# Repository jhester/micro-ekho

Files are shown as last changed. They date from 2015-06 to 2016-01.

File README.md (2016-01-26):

Micro Ekho
========

#### Summary
Micro Ekhos are simply miniature, battery powered, deployable versions of [Ekho](https://github.com/jhester/ekho) that can be put placed in energy environments of interest for extended periods of time. They transmit IV curve data over a Sub 1GHz frequency to a basestation, that collects and forwards to a desktop, a phone, or stores all data to an SD card.

This repo holds the hardware files, firmware (basestation, and node), mobile app viewing software (iOs, Android) and desktop viewing software, for Micro Ekho devices.

#### What is Ekho?
Ekho is a energy environment recorder, and emulator for the Internet of Things. It lets scientists and developers who work with tiny, batteryless, energy harevsting devices (think solar panels, piezos, peltier, RFID) have a repeatable testing environment. Without Ekho, verifying functionality for certain energy conditions, is impossible.

Our paper, "Ekho: Realistic and Repeatable Experimentation for Tiny Energy-Harvesting Sensors" describes the design and evaluation of a new tool for recording and replaying energy harvesting conditions. Energy harvesting is a necessity for many small, embedded sensing devices, that must operate maintenance-free for long periods of time. However, understanding how the environment changes and it's effects on device behavior has always been a source of frustration. Ekho allows system designers working with ultra low power devices, to realistically predict how new hardware and software configurations will perform before deployment. By taking advantage of electrical characteristics all energy sources share, Ekho is able to emulate many different energy sources (e.g., Solar, RF, Thermal, and Vibrational) and takes much of the guesswork out of experimentation with tiny, energy harvesting sensing systems.

This paper received the BEST PAPER Award at the 12th ACM Conference on Embedded Networked Sensor Systems (SenSys 2014).

For more information on the concept, design, and evaluation of Ekho, checkout [my website](http://josiahhester.comr).

#### Contents
The "basestation" aggregates the data from multiple "nodes," then sends this to the client application (which can be on a phone, tablet, or desktop) or logs to an SD card. Embedded C on a Teensy ARM chip.

The "desktop" folder contains an electron app that displays the data gathered.

The "hardware" folder contains all the EAGLE files for the micro ekho hardware.

The "mobile" renders the aggregate data on a screen, in real time. Written with apache cordova, HTML, CSS, JavaScript.

The "node" folder holds all the code for the Micro Ekho nodes that are attached to energy harvesters. These nodes send IV data to the "basestation" over the radio. Embedded C on an MSP430.

### Getting Started
Currently, this project is very much in progress, please contact me for more information, or raise an Issue.

#### License
Except for the desktop application made with Electron, everything else is MIT.

The MIT License (MIT)
Copyright (c) 2016 Josiah Hester

Permission is hereby granted, free of charge, to any person obtaining a copy of this software and associated documentation files (the "Software"), to deal in the Software without restriction, including without limitation the rights to use, copy, modify, merge, publish, distribute, sublicense, and/or sell copies of the Software, and to permit persons to whom the Software is furnished to do so, subject to the following conditions:

The above copyright notice and this permission notice shall be included in all copies or substantial portions of the Software.

THE SOFTWARE IS PROVIDED "AS IS", WITHOUT WARRANTY OF ANY KIND, EXPRESS OR IMPLIED, INCLUDING BUT NOT LIMITED TO THE WARRANTIES OF MERCHANTABILITY, FITNESS FOR A PARTICULAR PURPOSE AND NONINFRINGEMENT. IN NO EVENT SHALL THE AUTHORS OR COPYRIGHT HOLDERS BE LIABLE FOR ANY CLAIM, DAMAGES OR OTHER LIABILITY, WHETHER IN AN ACTION OF CONTRACT, TORT OR OTHERWISE, ARISING FROM, OUT OF OR IN CONNECTION WITH THE SOFTWARE OR THE USE OR OTHER DEALINGS IN THE SOFTWARE.

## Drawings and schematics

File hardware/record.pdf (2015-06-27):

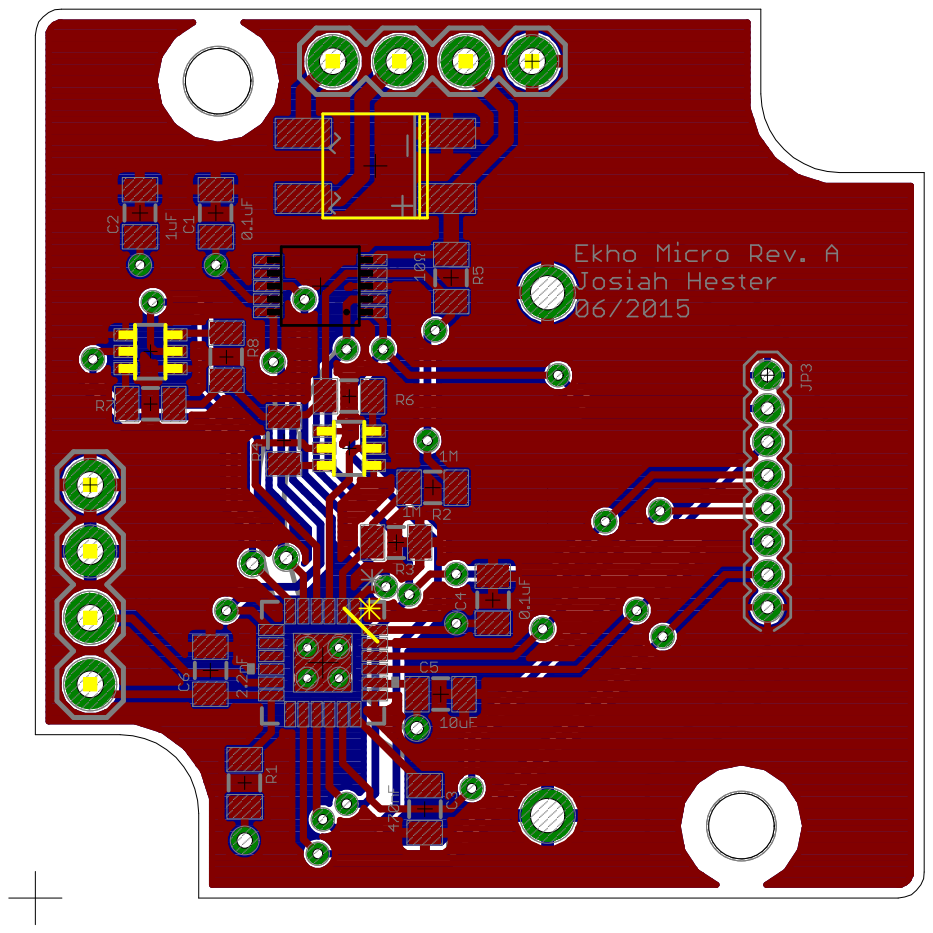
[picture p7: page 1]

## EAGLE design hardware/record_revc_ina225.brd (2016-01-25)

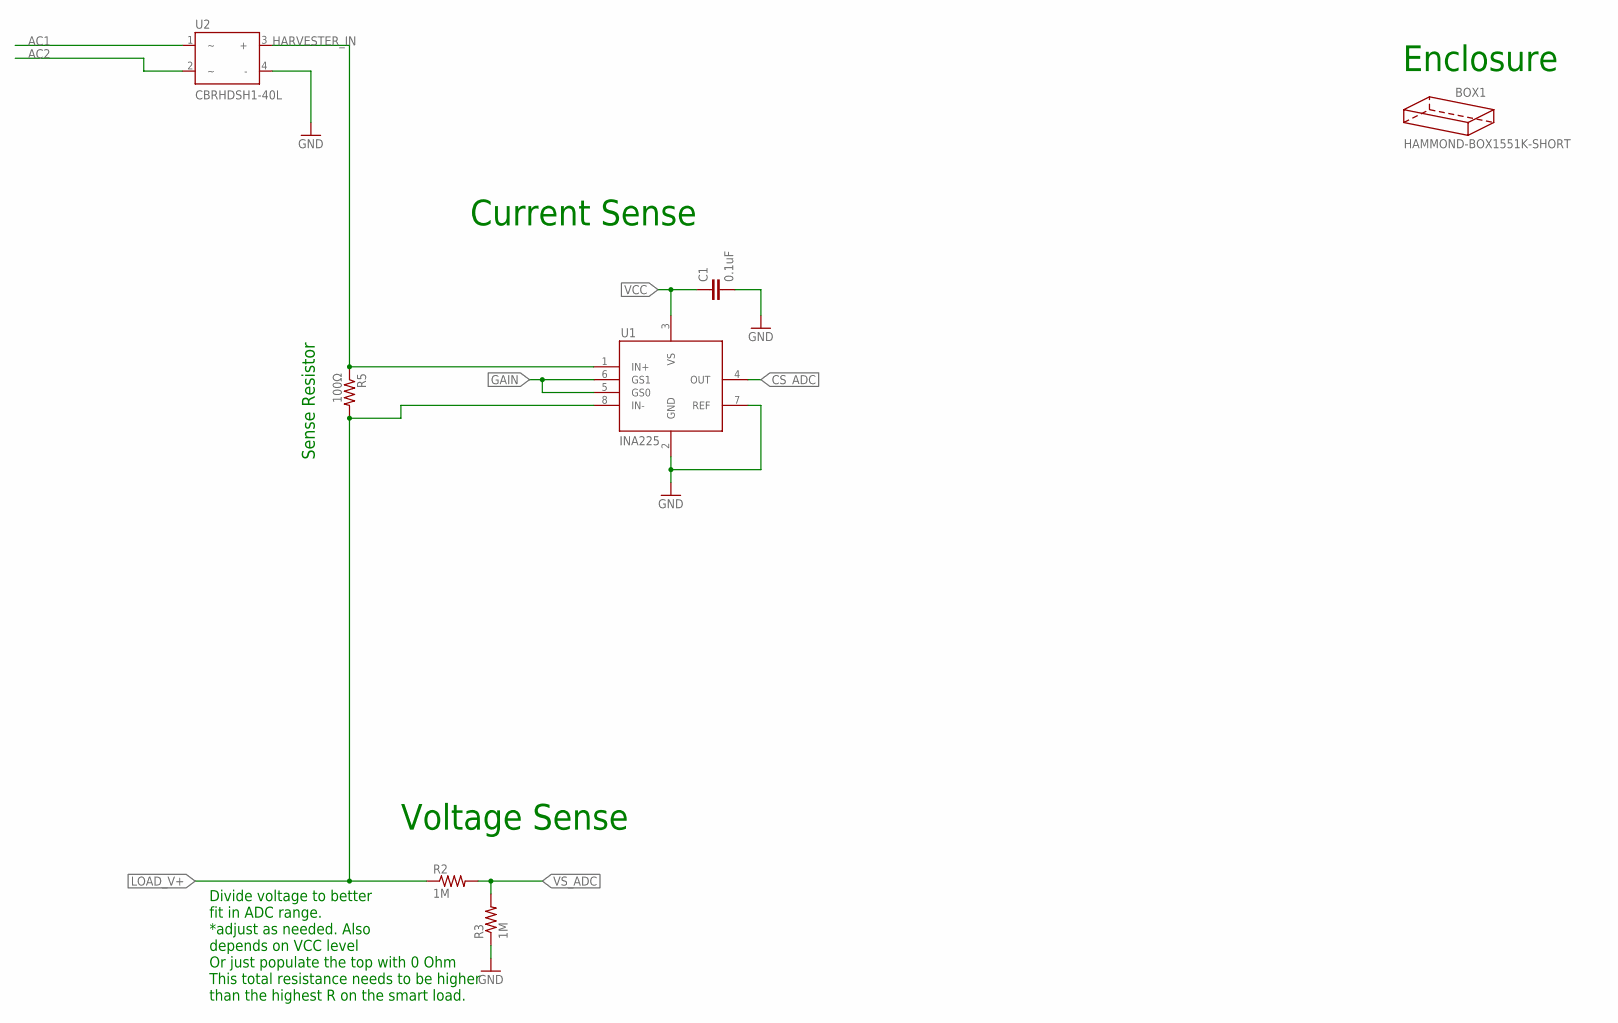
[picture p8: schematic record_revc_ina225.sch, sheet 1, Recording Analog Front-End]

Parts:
BOX1: HAMMOND-BOX1551K-SHORT; 1551K-SHORT
C1: 0.1uF; C0805
R2, R3: 1M; 0805
R5: 100Ω; 0805
U1: INA225; MSOP8
U2: CBRHDSH1-40L; HD_DIP4

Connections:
AC1: U2.1; also elsewhere on the board
AC2: U2.2; also elsewhere on the board
CS_ADC: U1.4 (OUT); also elsewhere on the board
GAIN: U1.5 (GS0), U1.6 (GS1); also elsewhere on the board
GND: C1.2, R3.1, U1.2 (GND), U1.7 (REF), U2.4 (-); also elsewhere on the board
HARVESTER_IN: R5.1, U1.1 (IN+), U2.3 (+); also elsewhere on the board
LOAD_V+: R2.1, R5.2, U1.8 (IN-); also elsewhere on the board
VCC: C1.1, U1.3 (VS); also elsewhere on the board
VS_ADC: R2.2, R3.2; also elsewhere on the board

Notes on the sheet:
Sense Resistor
Voltage Sense
Current Sense
Divide voltage to better fit in ADC range. *adjust as needed. Also depends on VCC level Or just populate the top with 0 Ohm This total resistance needs to be higher than the highest R on the smart load.
Enclosure

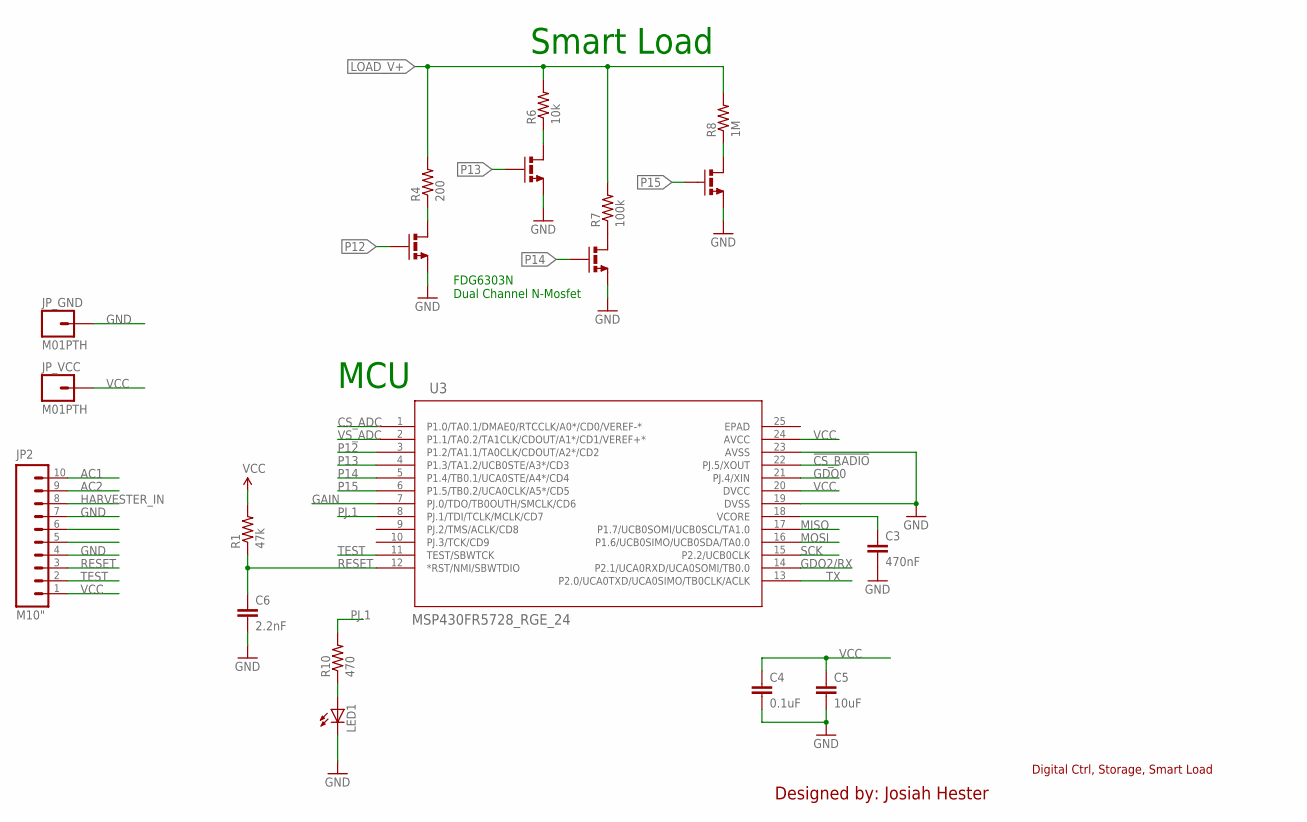
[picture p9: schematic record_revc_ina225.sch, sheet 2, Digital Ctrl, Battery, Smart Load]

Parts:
C3: 470nF; 0805
C4: 0.1uF; 0805
C5: 10uF; 0805
C6: 2.2nF; 0805
JP2: M10"; 1X10
JP_GND: M01PTH; 1X01
JP_VCC: M01PTH; 1X01
LED1: LED0603; LED-0603
R1: 47k; 0805
R4: 200; 0805
R6: 10k; 0805
R7: 100k; 0805
R8: 1M; 0805
R10: 470; 0805
U3: MSP430FR5728_RGE_24; RGE24_2P1X2P1
U4, U5: FDG6303N; SC70-6

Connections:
!CS_RADIO: U3.22 (PJ.5/XOUT); also elsewhere on the board
AC1: JP2.10; also elsewhere on the board
AC2: JP2.9; also elsewhere on the board
CS_ADC: U3.1 (P1.0/TA0.1/DMAE0/RTCCLK/A0*/CD0/VEREF-*); also elsewhere on the board
GAIN: U3.7 (PJ.0/TDO/TB0OUTH/SMCLK/CD6); also elsewhere on the board
GDO0: U3.21 (PJ.4/XIN); also elsewhere on the board
GDO2/RX: JP2.6, U3.14 (P2.1/UCA0RXD/UCA0SOMI/TB0.0); also elsewhere on the board
GND: C3.2, C4.2, C5.2, C6.2, JP2.4, JP2.7, JP_GND.1, LED1.C, U3.19 (DVSS), U3.23 (AVSS), U4.1 (S2), U4.4 (S1), U5.1 (S2), U5.4 (S1); also elsewhere on the board
HARVESTER_IN: JP2.8; also elsewhere on the board
LOAD_V+: R4.2, R6.2, R7.2, R8.2; also elsewhere on the board
MISO: U3.17 (P1.7/UCB0SOMI/UCB0SCL/TA1.0); also elsewhere on the board
MOSI: U3.16 (P1.6/UCB0SIMO/UCB0SDA/TA0.0); also elsewhere on the board
unnamed: C3.1, U3.18 (VCORE)
unnamed: R7.1, U5.3 (D1)
unnamed: R8.1, U5.6 (D2)
unnamed: R6.1, U4.6 (D2)
unnamed: R4.1, U4.3 (D1)
unnamed: LED1.A, R10.1
P12: U3.3 (P1.2/TA1.1/TA0CLK/CDOUT/A2*/CD2), U4.5 (G1)
P13: U3.4 (P1.3/TA1.2/UCB0STE/A3*/CD3), U4.2 (G2)
P14: U3.5 (P1.4/TB0.1/UCA0STE/A4*/CD4), U5.5 (G1)
P15: U3.6 (P1.5/TB0.2/UCA0CLK/A5*/CD5), U5.2 (G2)
PJ.1: R10.2, U3.8 (PJ.1/TDI/TCLK/MCLK/CD7)
RESET: C6.1, JP2.3, R1.1, U3.12 (*RST/NMI/SBWTDIO)
SCK: U3.15 (P2.2/UCB0CLK); also elsewhere on the board
TEST: JP2.2, U3.11 (TEST/SBWTCK)
TX: JP2.5, U3.13 (P2.0/UCA0TXD/UCA0SIMO/TB0CLK/ACLK)
VCC: C4.1, C5.1, JP2.1, JP_VCC.1, R1.2, U3.20 (DVCC), U3.24 (AVCC); also elsewhere on the board
VS_ADC: U3.2 (P1.1/TA0.2/TA1CLK/CDOUT/A1*/CD1/VEREF+*); also elsewhere on the board

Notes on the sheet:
Digital Ctrl, Storage, Smart Load
Designed by: Josiah Hester
MCU
Smart Load
FDG6303N Dual Channel N-Mosfet

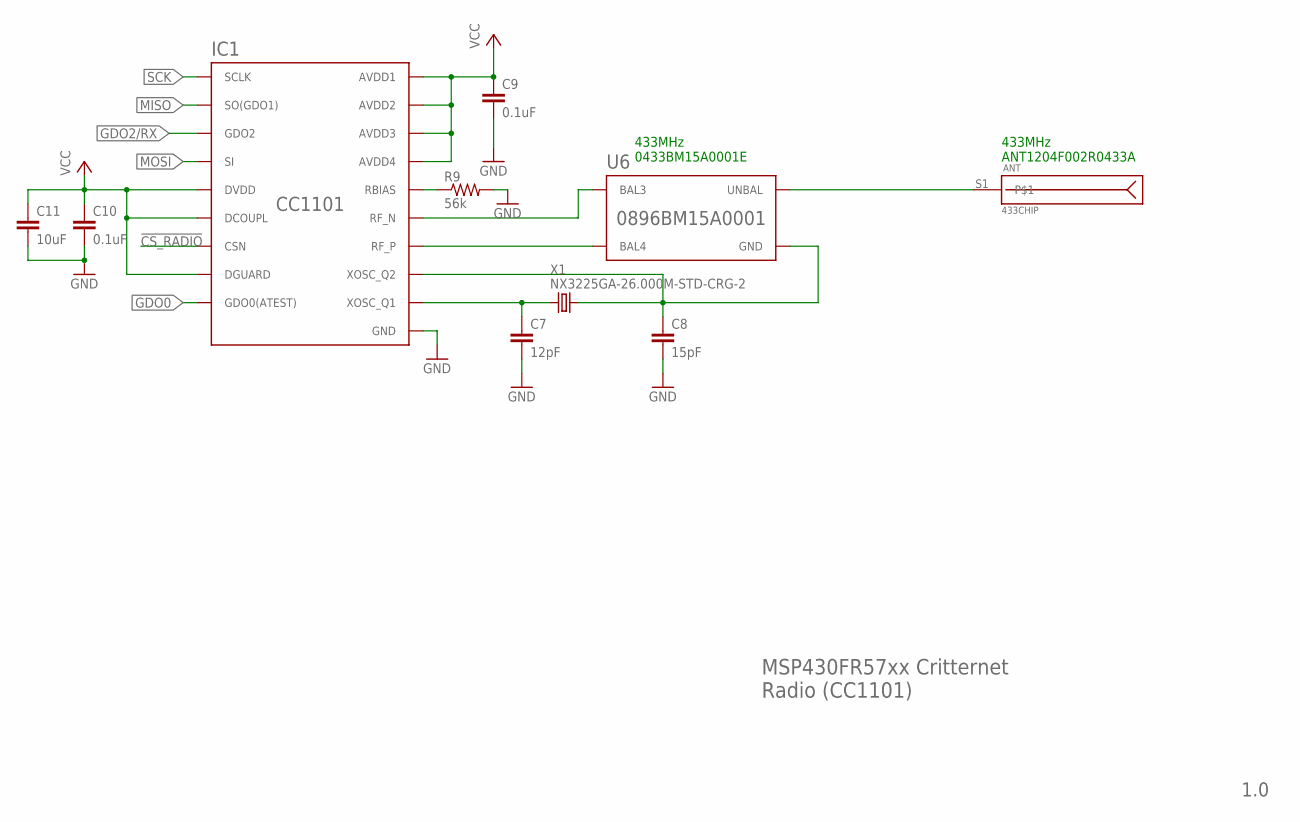
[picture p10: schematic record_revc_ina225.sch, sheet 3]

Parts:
ANT: 433CHIP; ANT-433-USP
C7: 12pF; 0603-CAP
C8: 15pF; 0603-CAP
C9: 0.1uF; 0603-CAP
C10: 0.1uF; C0805
C11: 10uF; 0805
IC1: CC1101; QLP20
R9: 56k; 0603
U6: 0896BM15A0001
X1: NX3225GA-26.000M-STD-CRG-2; XTAL-3.2X2.5

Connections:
!CS_RADIO: IC1.7 (CSN); also elsewhere on the board
GDO0: IC1.6 (GDO0(ATEST)); also elsewhere on the board
GDO2/RX: IC1.3 (GDO2); also elsewhere on the board
GND: C7.2, C8.2, C9.2, C10.2, C11.2, IC1.16 (GND), IC1.19 (GND), IC1.GND, IC1.GND1 (GND), IC1.GND2 (GND), IC1.GND3 (GND), IC1.GND4 (GND), IC1.GND5 (GND), R9.2; also elsewhere on the board
MISO: IC1.2 (SO(GDO1)); also elsewhere on the board
MOSI: IC1.20 (SI); also elsewhere on the board
unnamed: IC1.12 (RF_P), U6.4 (BAL4)
unnamed: IC1.13 (RF_N), U6.3 (BAL3)
unnamed: C7.1, IC1.8 (XOSC_Q1), X1.1
unnamed: IC1.17 (RBIAS), R9.1
unnamed: ANT.S1, U6.1 (UNBAL)
SCK: IC1.1 (SCLK); also elsewhere on the board
VCC: C9.1, C10.1, C11.1, IC1.4 (DVDD), IC1.5 (DCOUPL), IC1.9 (AVDD1), IC1.11 (AVDD2), IC1.14 (AVDD3), IC1.15 (AVDD4), IC1.18 (DGUARD); also elsewhere on the board
XOSC_Q2: C8.1, IC1.10 (XOSC_Q2), U6.2 (GND), U6.5 (GND), U6.6 (GND), X1.3 (2)

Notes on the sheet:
433MHz 0433BM15A0001E
MSP430FR57xx Critternet Radio (CC1101)
1.0
433MHz ANT1204F002R0433A

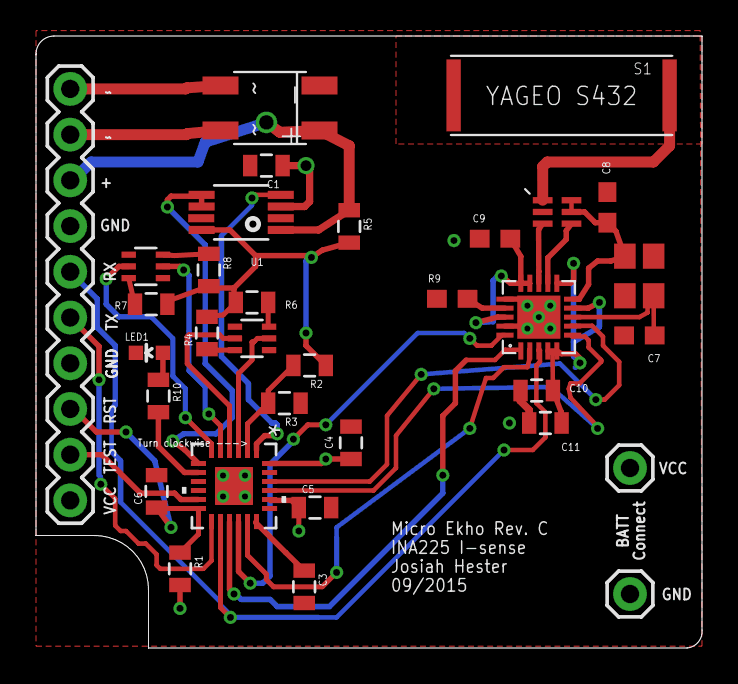
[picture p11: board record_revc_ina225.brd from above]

Board: 4 copper layers, 37.0 x 34.0 mm, 34 parts (0 on the bottom side), 35 nets.

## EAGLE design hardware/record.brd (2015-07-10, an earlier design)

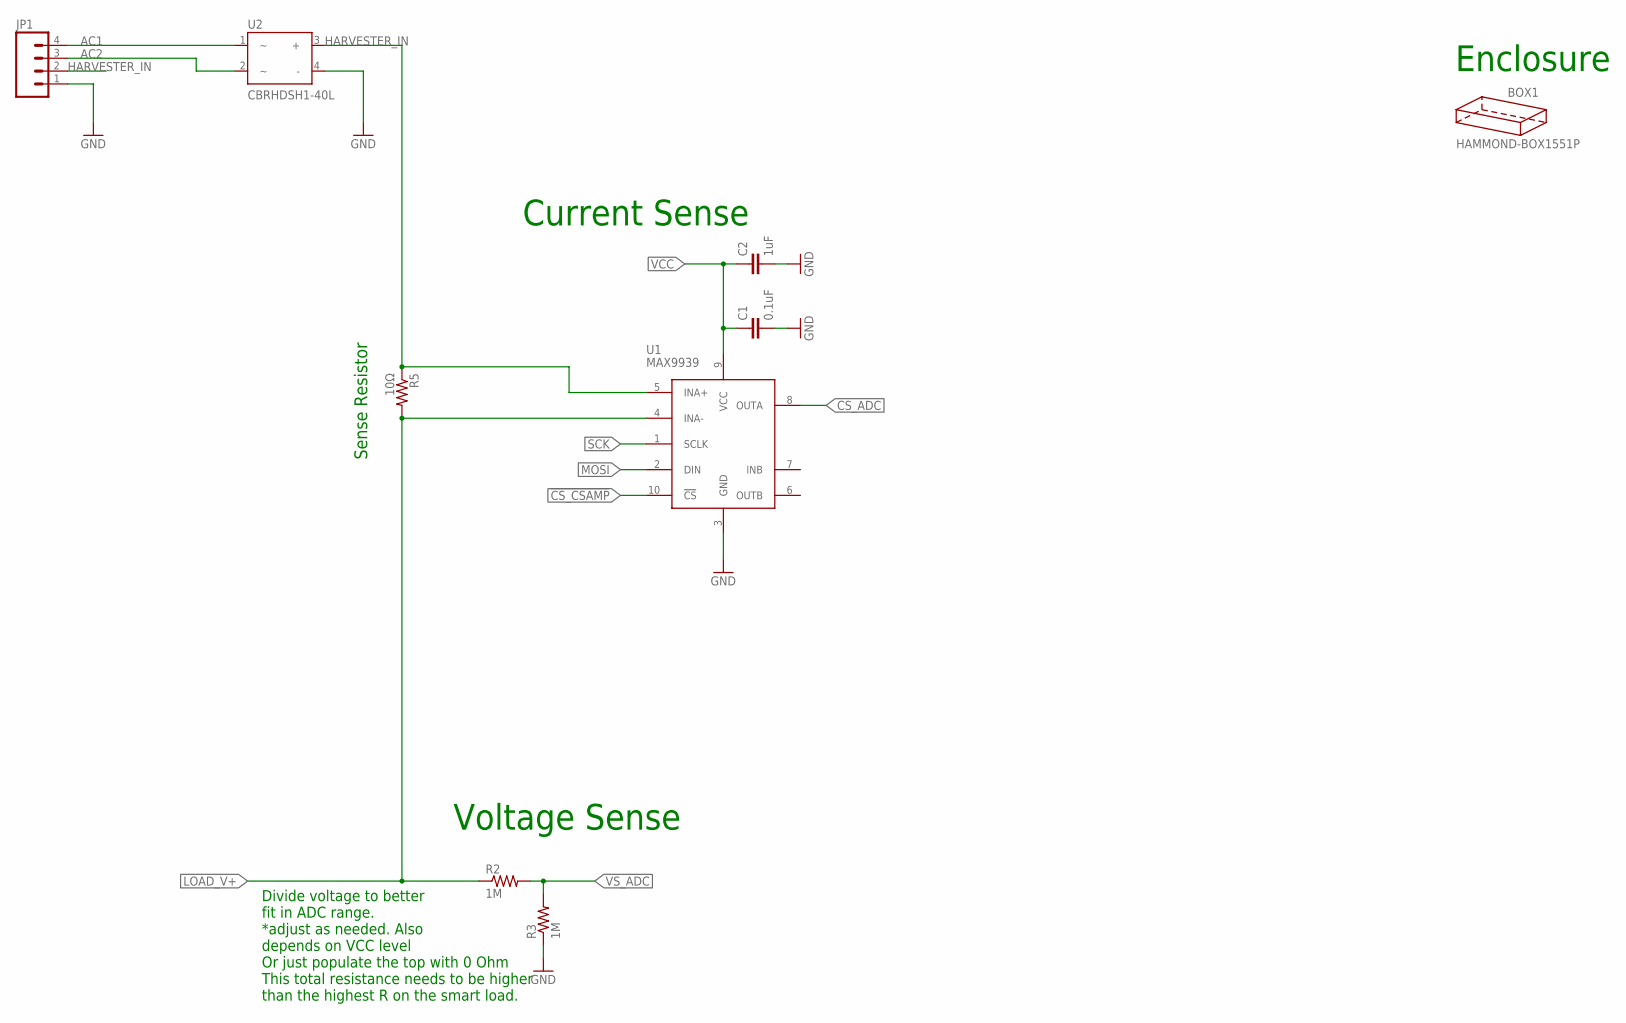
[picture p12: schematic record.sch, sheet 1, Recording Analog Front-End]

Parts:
BOX1: HAMMOND-BOX1551P; 1551P
C1: 0.1uF; C0805
C2: 1uF; C0805
JP1: M04PTH; 1X04
R2, R3: 1M; 0805
R5: 10Ω; 0805
U1: MAX9939; 10µMAX
U2: CBRHDSH1-40L; HD_DIP4

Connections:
!CS_CSAMP: U1.10 (!CS); also elsewhere on the board
AC1: JP1.4, U2.1
AC2: JP1.3, U2.2
CS_ADC: U1.8 (OUTA); also elsewhere on the board
GND: C1.2, C2.2, JP1.1, R3.1, U1.3 (GND), U2.4 (-); also elsewhere on the board
HARVESTER_IN: JP1.2, R5.1, U1.5 (INA+), U2.3 (+)
LOAD_V+: R2.1, R5.2, U1.4 (INA-); also elsewhere on the board
MOSI: U1.2 (DIN); also elsewhere on the board
SCK: U1.1 (SCLK); also elsewhere on the board
VCC: C1.1, C2.1, U1.9 (VCC); also elsewhere on the board
VS_ADC: R2.2, R3.2; also elsewhere on the board

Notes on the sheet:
Sense Resistor
Voltage Sense
Current Sense
Divide voltage to better fit in ADC range. *adjust as needed. Also depends on VCC level Or just populate the top with 0 Ohm This total resistance needs to be higher than the highest R on the smart load.
Enclosure

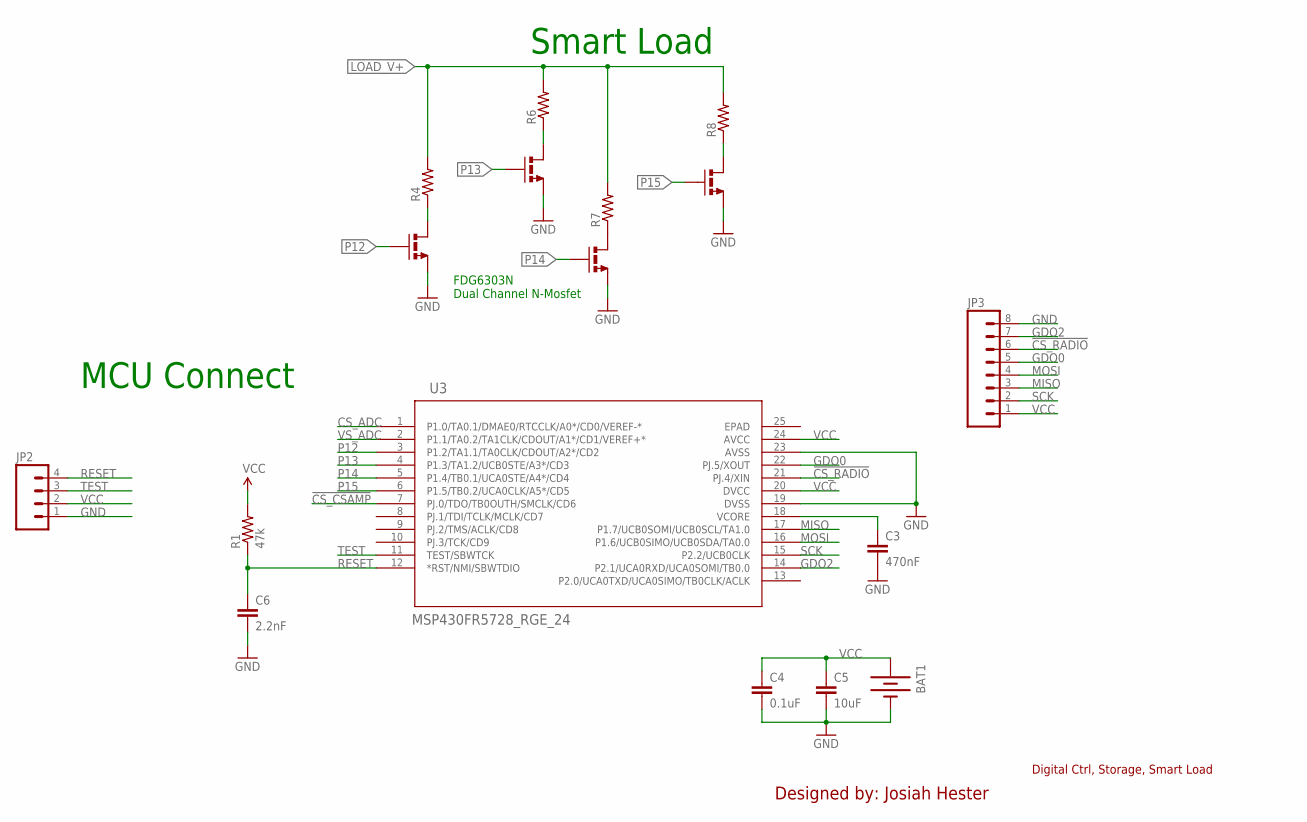
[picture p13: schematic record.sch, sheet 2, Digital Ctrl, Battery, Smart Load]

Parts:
BAT1: BATTERY20PTH; BATTCOM_20MM_PTH
C3: 470nF; 0805
C4: 0.1uF; 0805
C5: 10uF; 0805
C6: 2.2nF; 0805
JP2: M04PTH; 1X04
JP3: M081X08-1.27MM-PTH; 1X08-1.27MM
R1: 47k; 0805
R4, R6, R7, R8: 0.22OHM1/4W1%(0805); 0805
U3: MSP430FR5728_RGE_24; RGE24_2P1X2P1
U4, U5: FDG6303N; SC70-6

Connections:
!CS_CSAMP: U3.7 (PJ.0/TDO/TB0OUTH/SMCLK/CD6); also elsewhere on the board
!CS_RADIO: JP3.6, U3.21 (PJ.4/XIN)
CS_ADC: U3.1 (P1.0/TA0.1/DMAE0/RTCCLK/A0*/CD0/VEREF-*); also elsewhere on the board
GDO0: JP3.5, U3.22 (PJ.5/XOUT)
GDO2: JP3.7, U3.14 (P2.1/UCA0RXD/UCA0SOMI/TB0.0)
GND: BAT1.2 (-), C3.2, C4.2, C5.2, C6.2, JP2.1, JP3.8, U3.19 (DVSS), U3.23 (AVSS), U4.1 (S2), U4.4 (S1), U5.1 (S2), U5.4 (S1); also elsewhere on the board
LOAD_V+: R4.2, R6.2, R7.2, R8.2; also elsewhere on the board
MISO: JP3.3, U3.17 (P1.7/UCB0SOMI/UCB0SCL/TA1.0)
MOSI: JP3.4, U3.16 (P1.6/UCB0SIMO/UCB0SDA/TA0.0); also elsewhere on the board
unnamed: C3.1, U3.18 (VCORE)
unnamed: R7.1, U5.3 (D1)
unnamed: R8.1, U5.6 (D2)
unnamed: R6.1, U4.6 (D2)
unnamed: R4.1, U4.3 (D1)
P12: U3.3 (P1.2/TA1.1/TA0CLK/CDOUT/A2*/CD2), U4.5 (G1)
P13: U3.4 (P1.3/TA1.2/UCB0STE/A3*/CD3), U4.2 (G2)
P14: U3.5 (P1.4/TB0.1/UCA0STE/A4*/CD4), U5.5 (G1)
P15: U3.6 (P1.5/TB0.2/UCA0CLK/A5*/CD5), U5.2 (G2)
RESET: C6.1, JP2.4, R1.1, U3.12 (*RST/NMI/SBWTDIO)
SCK: JP3.2, U3.15 (P2.2/UCB0CLK); also elsewhere on the board
TEST: JP2.3, U3.11 (TEST/SBWTCK)
VCC: BAT1.1 (+), C4.1, C5.1, JP2.2, JP3.1, R1.2, U3.20 (DVCC), U3.24 (AVCC); also elsewhere on the board
VS_ADC: U3.2 (P1.1/TA0.2/TA1CLK/CDOUT/A1*/CD1/VEREF+*); also elsewhere on the board

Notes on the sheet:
Digital Ctrl, Storage, Smart Load
Designed by: Josiah Hester
MCU Connect
Smart Load
FDG6303N Dual Channel N-Mosfet

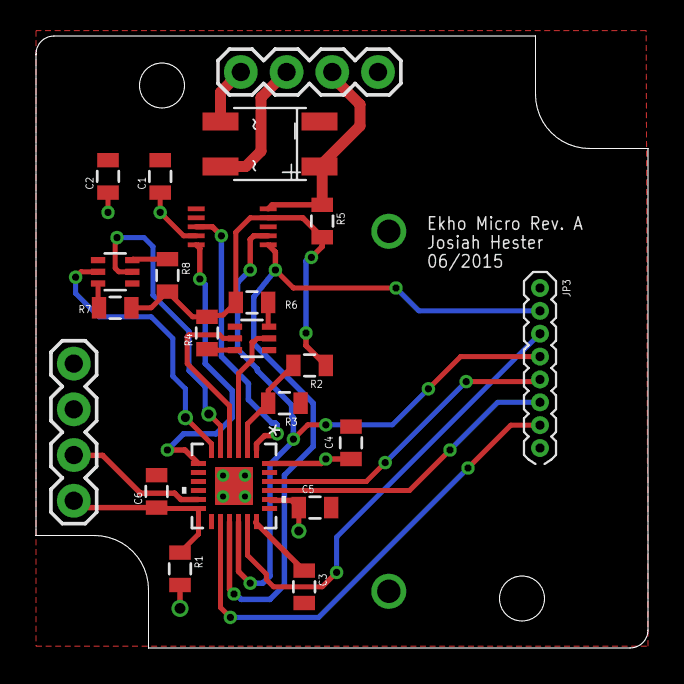
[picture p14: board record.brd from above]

Board: 4 copper layers, 34.0 x 34.0 mm, 24 parts (1 on the bottom side), 26 nets.

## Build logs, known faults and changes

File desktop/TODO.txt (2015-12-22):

TODO
√ - Add pause / resume button
√ - Select box with Current, Voltage, and Power
√ - Get axis labels
√ - Change rendered based on textbox
√ - Give slider for different sizes (snap to 10s, 5s, 1s, 0.1s)
- Add button to connect / start datastream using node executable.
	Make Application out of serial node thing, or make clickable script for data_stream
	Ekho for dummies 
- Give Micro Ekho have pinless programmer
- Figure out correct datarate, and communication between basestation, to coordinate a TDMA for micro ekhos
- Make Application have a logo (Ekho)

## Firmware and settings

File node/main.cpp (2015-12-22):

/* 
 * Send IV-curves (raw IV points really) over-the-air as fast as possible to anyone listeneing
 * 
 * 
 * 
 * Author: Josiah Hester
 */
#include <msp430fr5728.h>
#include "cc1101.h"
#include <string.h>
#define SAMPLE_DELAY 1600
#define DELAY_BETWEEN 1600
#define SAMPLES 5
#define SAMPLE_SIZE 2
#define BUF_SIZE_BYTES (SAMPLE_SIZE * SAMPLES)
#define RX_BUFFER_SIZE (SAMPLE_SIZE * SAMPLES + 1) 
#define TX_BUFFER_SIZE 61
#define SEND_DELAY_TICKS 1000
#define MAX_NODES 4
#define TOTAL_NETWORK_TIME (MAX_NODES * SEND_DELAY_TICKS)
#define LOOP_TIMES (SAMPLES) // Number of items in array
#define REF_SELECTOR ADC10SREF_1
 
uint8_t tx_buffer[TX_BUFFER_SIZE]={0};
uint8_t rx_buffer[RX_BUFFER_SIZE]={0};
uint16_t v_samples[SAMPLES]={0};
uint16_t i_samples[SAMPLES]={0};
volatile uint8_t burstnum,i,flag;
uint16_t sleep_time;
uint8_t loop_index;

void init_clocks() {
	CSCTL0_H = 0xA5;
	CSCTL1 = DCORSEL + DCOFSEL_3; // Set to 24MHz DCO clock
	CSCTL2 = SELA_1 + SELS_3 + SELM_3;        // set ACLK = VLO; MCLK = DCO
	CSCTL3 = DIVA_0 + DIVS_1 + DIVM_1;        // set all dividers, Div by 1 for 8MHz clock speed
}

uint16_t sample_voltage() {
	ADC10CTL0 &= ~ADC10ENC;
	ADC10MCTL0 = ADC10INCH_1 + REF_SELECTOR;
	ADC10CTL0 |= ADC10ENC + ADC10SC;
	while(ADC10CTL1 & ADC10BUSY);
	uint16_t retval = ADC10MEM0;
	if(retval < MAX_NODES) retval = MAX_NODES+1; // The low values are reserved, since they are noise anyway on the ADC
	return retval;
}

uint16_t sample_current() {
	ADC10CTL0 &= ~ADC10ENC;
	ADC10MCTL0 = ADC10INCH_0 + REF_SELECTOR;
	ADC10CTL0 |= ADC10ENC + ADC10SC;
	while(ADC10CTL1 & ADC10BUSY);
	uint16_t retval = ADC10MEM0;
	if(retval < MAX_NODES) retval = MAX_NODES+1; // The low values are reserved, since they are noise anyway on the ADC
	return retval;
}

void set_gain_high() {
	PJDIR |= BIT0;
	PJOUT |= BIT0;
}

void set_gain_low() {
	PJDIR |= BIT0;
	PJOUT &= ~BIT0;
}

void led_init() {
	PJDIR |= BIT1;
}

void led_on() {
	PJOUT |= BIT1;
}

void led_off() {	
	PJOUT &= ~BIT1;
}

void led_toggle() {	
	PJOUT ^= BIT1;
}

void smart_load_init() {
    P1DIR |= BIT2 + BIT3 + BIT4 + BIT5;
    P1OUT &= ~(BIT2 + BIT3 + BIT4 + BIT5);
}

void smart_load_off() {
	P1OUT &= ~(BIT2 + BIT3 + BIT4 + BIT5);
}

void smart_load() {
    P1OUT |= BIT2;
    __delay_cycles(SAMPLE_DELAY);
    v_samples[0] = sample_voltage();
    i_samples[0] = sample_current();
    __delay_cycles(DELAY_BETWEEN);
    P1OUT &= ~(BIT2 + BIT3 + BIT4 + BIT5);

    P1OUT |= BIT3;
    __delay_cycles(SAMPLE_DELAY);
    v_samples[1] = sample_voltage();
    i_samples[1] = sample_current();
    __delay_cycles(DELAY_BETWEEN);
    P1OUT &= ~(BIT2 + BIT3 + BIT4 + BIT5);

    P1OUT |= BIT4;
    __delay_cycles(SAMPLE_DELAY);
    v_samples[2] = sample_voltage();
    i_samples[2] = sample_current();  
    __delay_cycles(DELAY_BETWEEN);
    P1OUT &= ~(BIT2 + BIT3 + BIT4 + BIT5);

    P1OUT |= BIT5;
    __delay_cycles(SAMPLE_DELAY);
    v_samples[3] = sample_voltage();
    i_samples[3] = sample_current();
    __delay_cycles(DELAY_BETWEEN);

    P1OUT &= ~(BIT2 + BIT3 + BIT4 + BIT5);
    __delay_cycles(SAMPLE_DELAY);
    v_samples[4] = sample_voltage();
    i_samples[4] = sample_current();
    __delay_cycles(DELAY_BETWEEN);
}

void voltage_load() {
	P1OUT |= BIT5;
    __delay_cycles(SAMPLE_DELAY);
    v_samples[3] = sample_voltage();
    i_samples[3] = sample_current();
    __delay_cycles(DELAY_BETWEEN);
}

void current_load() {
	P1OUT &= ~(BIT2 + BIT3 + BIT4 + BIT5);
    __delay_cycles(SAMPLE_DELAY);
    v_samples[0] = sample_voltage();
    i_samples[0] = sample_current();
    __delay_cycles(DELAY_BETWEEN);
    
}
int main(void){
	uint16_t max = 0, j=0;
	uint16_t temp = 0;
	
	//Stop watchdog timer
	WDTCTL = WDTPW + WDTHOLD;

	// FET pins for smart load all low
	smart_load_init();
	// Set gain on INA225
	//set_gain_low();
	set_gain_high();
	// LED
	led_init();
	// Setup clocks
	init_clocks();
    
	// Configure ADC for V_SENSE and I_SENSE
	P1SEL0 |= BIT1 + BIT0;
	P1SEL1 |= BIT1 + BIT0;
	ADC10CTL0 &= ~ADC10ENC;
	ADC10CTL0 |= ADC10ON + ADC10SHT_0;
	ADC10CTL1 |= ADC10DIV_4 + ADC10SHP;
	ADC10CTL2 |= ADC10RES + ADC10PDIV_0; // 10-bit results
	ADC10MCTL0 = ADC10INCH_1 + REF_SELECTOR;
	ADC10CTL0 |= ADC10ENC;

	// By default, REFMSTR=1 => REFCTL is used to configure the internal reference
	while(REFCTL0 & REFGENBUSY);              // If ref generator busy, WAIT                                          
	REFCTL0 |= REFVSEL_0+REFON;               // Select internal ref = 1.5V, Internal Reference ON   
	__delay_cycles(1000);                      // ref delay  

	// Init results 
	tx_buffer[0] = DEVICE_ID;

	// Radio startup
	Radio.Init();	
	Radio.SetDataRate(3); // Needs to be the same in Tx and Rx
	Radio.SetLogicalChannel(0); // Needs to be the same in Tx and Rx	
	Radio.SetTxPower(0);
	Radio.Sleep();
	
	// Main loop
	while(1) {	
		led_toggle();
    	
		// Get three IV curves to fill up packet
    	for(j=0;j<3;j++) {
    		smart_load();
			memcpy(&tx_buffer[1+BUF_SIZE_BYTES * 2 * j], v_samples, BUF_SIZE_BYTES); 
    		memcpy(&tx_buffer[1+BUF_SIZE_BYTES+BUF_SIZE_BYTES * 2 * j], i_samples, BUF_SIZE_BYTES); 
    	}

    	// Turn on radio, for speed, don't sleep / wakeup
		Radio.Wakeup();
		__delay_cycles(100);
		Radio.SendData(tx_buffer, TX_BUFFER_SIZE);
		Radio.Sleep();
	}
	return 1;
}

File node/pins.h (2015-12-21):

#ifndef PINS_h
#define PINS_h

/* ------------------------------------------------------------------------------------------------
 *                                      GDO0 Pin Configuration
 * ------------------------------------------------------------------------------------------------
 */
#define GDO0_BIT__                     4
#define GDO0_PORT__                    J
#define CONFIG_GDO0_PIN_AS_INPUT()       st( INFIX( P, GDO0_PORT__, SEL0 ) &= ~BV(GDO0_BIT__); INFIX( P, GDO0_PORT__, DIR ) &= ~BV(GDO0_BIT__); ) /* clear pin special function default */
#define GDO0_PIN_IS_HIGH()               ( INFIX( P, GDO0_PORT__, IN ) & BV(GDO0_BIT__))


#define GDO0_INT_VECTOR                  INFIX( PORT, GDO0_PORT__, _VECTOR )
#define ENABLE_GDO0_INT()                st( INFIX( P, GDO0_PORT__, IE )  |=  BV(GDO0_BIT__); ) /* atomic operation */
#define DISABLE_GDO0_INT()               st( INFIX( P, GDO0_PORT__, IE )  &= ~BV(GDO0_BIT__); ) /* atomic operation */
#define GDO0_INT_IS_ENABLED()             (  INFIX( P, GDO0_PORT__, IE )  &   BV(GDO0_BIT__) )
#define CLEAR_GDO0_INT_FLAG()            st( INFIX( P, GDO0_PORT__, IFG ) &= ~BV(GDO0_BIT__); ) /* atomic operation */
#define GDO0_INT_FLAG_IS_SET()            (  INFIX( P, GDO0_PORT__, IFG ) &   BV(GDO0_BIT__) )
#define CONFIG_GDO0_RISING_EDGE_INT()    st( INFIX( P, GDO0_PORT__, IES ) &= ~BV(GDO0_BIT__); ) /* atomic operation */
#define CONFIG_GDO0_FALLING_EDGE_INT()   st( INFIX( P, GDO0_PORT__, IES ) |=  BV(GDO0_BIT__); ) /* atomic operation */


/* ------------------------------------------------------------------------------------------------
 *                                      GDO2 Pin Configuration
 * ------------------------------------------------------------------------------------------------
 */
#define GDO2_BIT__                     1
#define GDO2_PORT__                    2
#define CONFIG_GDO2_PIN_AS_INPUT()       st( INFIX( P, GDO2_PORT__, SEL0 ) &= ~BV(GDO2_BIT__); INFIX( P, GDO2_PORT__, DIR ) &= ~BV(GDO2_BIT__);) /* clear pin special function default */
#define GDO2_PIN_IS_HIGH()               ( INFIX( P, GDO2_PORT__, IN ) & BV(GDO2_BIT__))

#define GDO2_INT_VECTOR                  INFIX( PORT, GDO2_PORT__, _VECTOR )
#define ENABLE_GDO2_INT()                st( INFIX( P, GDO2_PORT__, IE )  |=  BV(GDO2_BIT__); ) /* atomic operation */
#define DISABLE_GDO2_INT()               st( INFIX( P, GDO2_PORT__, IE )  &= ~BV(GDO2_BIT__); ) /* atomic operation */
#define GDO2_INT_IS_ENABLED()             (  INFIX( P, GDO2_PORT__, IE )  &   BV(GDO2_BIT__) )
#define CLEAR_GDO2_INT_FLAG()            st( INFIX( P, GDO2_PORT__, IFG ) &= ~BV(GDO2_BIT__); ) /* atomic operation */
#define GDO2_INT_FLAG_IS_SET()            (  INFIX( P, GDO2_PORT__, IFG ) &   BV(GDO2_BIT__) )
#define CONFIG_GDO2_RISING_EDGE_INT()    st( INFIX( P, GDO2_PORT__, IES ) &= ~BV(GDO2_BIT__); ) /* atomic operation */
#define CONFIG_GDO2_FALLING_EDGE_INT()   st( INFIX( P, GDO2_PORT__, IES ) |=  BV(GDO2_BIT__); ) /* atomic operation */


/* ------------------------------------------------------------------------------------------------
 *                                      SPI Configuration
 * ------------------------------------------------------------------------------------------------
 */

/* CSn Pin Configuration */
#define SPI_CSN_GPIO_BIT__             5
#define SPI_CONFIG_CSN_PIN_AS_OUTPUT()   st( PJDIR |=  BV(SPI_CSN_GPIO_BIT__); )
#define SPI_DRIVE_CSN_HIGH()             st( PJOUT |=  BV(SPI_CSN_GPIO_BIT__); ) /* atomic operation */
#define SPI_DRIVE_CSN_LOW()              st( PJOUT &= ~BV(SPI_CSN_GPIO_BIT__); ) /* atomic operation */
#define SPI_CSN_IS_HIGH()                 (  PJOUT &   BV(SPI_CSN_GPIO_BIT__) )

/* SCLK Pin Configuration */
#define SPI_SCLK_GPIO_BIT__            2
#define SPI_CONFIG_SCLK_PIN_AS_OUTPUT()  st( P2DIR |=  BV(SPI_SCLK_GPIO_BIT__); )
#define SPI_DRIVE_SCLK_HIGH()            st( P2OUT |=  BV(SPI_SCLK_GPIO_BIT__); )
#define SPI_DRIVE_SCLK_LOW()             st( P2OUT &= ~BV(SPI_SCLK_GPIO_BIT__); )

/* SI Pin Configuration */
#define SPI_SI_GPIO_BIT__              6
#define SPI_CONFIG_SI_PIN_AS_OUTPUT()    st( P1DIR |=  BV(SPI_SI_GPIO_BIT__); )
#define SPI_DRIVE_SI_HIGH()              st( P1OUT |=  BV(SPI_SI_GPIO_BIT__); )
#define SPI_DRIVE_SI_LOW()               st( P1OUT &= ~BV(SPI_SI_GPIO_BIT__); )

/* SO Pin Configuration */
#define SPI_SO_GPIO_BIT__              7
#define SPI_CONFIG_SO_PIN_AS_INPUT()     st( P1DIR &= ~BV(SPI_SO_GPIO_BIT__);)
#define SPI_SO_IS_HIGH()                 ( P1IN & BV(SPI_SO_GPIO_BIT__) )
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

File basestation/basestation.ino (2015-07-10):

#include <ELECHOUSE_CC1101.h>
#define MAX_NODES 4
#define LISTEN_TIME 120
#define MIN_PACKET_SIZE 10
unsigned long lastrx[MAX_NODES+1] = {0}; 
unsigned long elapsed; 
void setup()
{
  Serial.begin(115200);
  Serial1.begin(57600);
  ELECHOUSE_cc1101.Init();
  ELECHOUSE_cc1101.SetDataRate(3); // Needs to be the same in Tx and Rx
  ELECHOUSE_cc1101.SetLogicalChannel(1); // Needs to be the same as receiver
  ELECHOUSE_cc1101.SetTxPower(1);
  ELECHOUSE_cc1101.SetReceive();
}

byte RX_buffer[61]={0};
byte TX_buffer[61]={0};
byte sizerx,i,flag;
byte node_id=0;
// TODO Make loop
// Channel hopping listen:
// Listen on each channel for 100 ms (configurable)
// Log channel info (the most recent maxes and start index) to BT
// Final in transmission is the index, maybe do some dat parsing here
void loop()
{
  for(int i=0;i<MAX_NODES;i++) {
    elapsed = millis();
    ELECHOUSE_cc1101.SetLogicalChannel(i); // Needs to be the same as receiver
    ELECHOUSE_cc1101.SetReceive();
    Serial.print("NDX=");
    Serial.println(i);
    while(millis() < elapsed + LISTEN_TIME) {
      // Listen 
      if(ELECHOUSE_cc1101.CheckReceiveFlag()) {
        sizerx=ELECHOUSE_cc1101.ReceiveData(RX_buffer);
        if(sizerx < MIN_PACKET_SIZE) continue;
        Serial.print(RX_buffer[0]);
        Serial.print(",");
        for(int j=1;j<sizerx;j+=2) {
          Serial.print((RX_buffer[j+1] << 8) | RX_buffer[j]);
          Serial.print(",");
        }
        Serial.println();

        // Log data points over bluetooth
        // Send ID, loop index in circular buffer, and then buffer
        Serial1.write(i);
        Serial1.write(RX_buffer, 19);
      }
    }
  }
}

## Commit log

2015-06-27 Put hardware, firmware, and software in one place for micro ecko.
    [record.brd, record.sch]
2015-06-27 Added in control for the micro echo circuitry
2015-06-27 Starter basestation code for Teensy.
2015-07-09 App look and UI functionality pretty much all done for demo. Rewrote duty cycle with basestation to listen for a time on each channel. Changed node code to broadcast on a single channel every 100ms. 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
    [basestation.ino]
2015-07-10 Final demo for California. Everything works well. Four nodes stress test worked great. Not awesome with quick changing energy harvesters like piezo though.
    [record.brd, record.sch]
2015-12-21 New hardware, new software for clients.
    [record_revb.brd, record_revb.sch, record_revc_ad8228.brd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]
2015-12-22 Version 0.1 ----- CHANGELOG: - Added pause / resume button on upper right - Added radio selection for displaying Current, Voltage, or Power - Added axis labels to graphs - Added radio selection for d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
2016-01-25 Final hardware for circuit hub
    [record_revc_ina225.brd, record_revc_ina225.sch]

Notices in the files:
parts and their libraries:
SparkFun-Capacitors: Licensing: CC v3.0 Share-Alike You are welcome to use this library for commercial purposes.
